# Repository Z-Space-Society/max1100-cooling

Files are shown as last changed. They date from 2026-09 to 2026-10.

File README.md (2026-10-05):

# max1100-cooling

Printed ducts for cooling the Intel Data Center GPU Max 1100, a passive 300 W
server card, with ordinary fans. First target is a single card in **Salmon**
(Lian Li LANCOOL 216 tower). The per-card part carries over to a four-card
plenum in a 4U chassis.

- [Dimensions](docs/dimensions.md): card, column and chassis measurements,
  datasheet and hand-measured
- [Cooling](docs/cooling.md): the problem, design decisions, fan choice, test method
- [RackChoice 4U](docs/rackchoice-4u.md): the quad's chassis — what fits, what's
  still unmeasured
- Project log and host notes live in SCNVault: `Projects/Max 1100 Notes/` for
  the single card, `Projects/QuadBox/` for the four-card appliance

## Terminology

Use these names every time. **Do not use front, back, top, bottom, left or
right on their own.** Left and right are only allowed with a named view (below).

### The card

```
                          SIDE VIEW (looking at the shroud side)

   I/O end                                                     tail end
     ┃ ┌───────────────────────── top edge ──────────────────────────┐
     ┃ │                                                             │▒ bay  ══ extension
     ┃ │                    shroud side (cover)                      │▒         bracket
     ┃ │                                                             │▒
     ┃ └──────┬▄▄▄▄▄▄▄▄▄▄▄▄┬───────── finger edge ───────────────────┘
     ┃        gold fingers
  I/O bracket

   ◀── into the card (−Z)                                   out past the tail (+Z) ──▶
```

```
                 TAIL VIEW (the default): standing past the tail end,
                 looking into the bay, shroud side up. Schematic, not to scale.
                 This is Rhino's Top view of the card adapter models.

                                   SHROUD SIDE  (+Y)
                ┌────────────────────────────────────────────────────┐  ┬
                │   ┌──────────────────────────────────────────┐     │  │
   FINGER EDGE  │ ● │▓▓▓▓▓▓▓▓▓▓▓▓▓▓▓▓ fin band ▓▓▓▓▓▓▓▓▓▓▓▓▓▓▓▓│     │  │  TOP EDGE
      (−X)   ◀──┤   │              bay opening                 │ 12V ├──▶   (+X)
                │ ● │      base plate · PCB · headers          │ 2x6 │  │
                │   └──────────────────────────────────────────┘     │  │ 38.64
                └────────────────────────────────────────────────────┘  ┴ thickness
                                    PCB SIDE  (−Y)
                ├──────────────────────── 111.15 height ─────────────┤

                ● = extension bracket mounting holes (finger side)
                +Z points out of the page, toward you (out past the tail)
```

| Term | Means | Avoid saying |
|---|---|---|
| **I/O end** | End with the PCIe I/O bracket. Air **exits** here. Sits at the rear of a case. | back, rear, front |
| **Tail end** | Opposite end: the bay, fins, 12V-2x6, extension bracket. Air **enters** here. | front, back, end |
| **Finger edge** | Long edge with the PCIe gold fingers. Plugs into the board. | bottom |
| **Top edge** | Long edge opposite the fingers. Black strip (bridge cover?) runs along it. | top (alone) |
| **Shroud side** | Face covered by the shroud cover. The fins sit against it inside. Older notes: "shroud top". "Up" in the tail view. | top, front, cooler side |
| **PCB side** | Opposite face: the back of the PCB, where the extension bracket plate sits. "Down" in the tail view. | back, bottom |
| **Length** | I/O end → tail end. 266.7 (312 with extension bracket). | |
| **Height** | Finger edge → top edge. 111.15. | width |
| **Thickness** | Shroud side → PCB side. **38.64** measured, not the datasheet's 34.35. | width, depth |

### The tail end

| Term | Means |
|---|---|
| **Shroud end plane** | Plane of the shroud's end at the tail. Z = 0. All "into the card" and "past the tail" distances measure from here. |
| **Bay** | The recessed pocket at the tail end. Not a flat face. |
| **Opening** | The bay's mouth at the shroud end plane, where the tube goes in. |
| **Fin band** | The fin stack as seen in the bay: a band along the shroud side. |
| **Fin face** | The fins' exposed ends, 37 to 39 into the bay. |
| **Fin throat** | The area of fin face air can actually enter. Not yet calipered. |
| **Connector column** | The part of the bay beside the fins with the 12V-2x6 (top-edge side), headers (CNSPI1, CNAMC1, SWAMC1). Stays open to the room. |
| **12V-2x6** | Power connector. Top-edge side of the tail end, toward the PCB side. Plugs in axially, needs ~35 straight cable. |
| **Extension bracket** | Flat L-plate on the PCB side, reaches 45 past the tail to a server card guide. Stays on: its screws now clamp the card adapter to the card. |
| **Bracket mounting holes** | The two threaded holes on the card, finger side of the tail end, that the extension bracket screws into (Torx T8). 19 apart (Katie). The adapter's bracket holes line up with these. |
| **Bracket plate** | The part of the extension bracket lying against the PCB side. |

### Card adapter (current design)

The printed piece that joins the GPU's own parts (the bay, the shroud end
plane, the extension bracket) to the printed ducting. Everything after it
(flare, fan) plugs into it. The working base since 2026-09-21: Katie's Rhino
model, adjusted here.

```
   CARD ADAPTER V2 in the tail view: flange face toward you, tube going away into the bay.

                                      shroud side ↑
      ┌──────────────────────────────────────────────────────────────┐ ┬ 2
      │      ┌─────────────────────────────────────────────────┐     │ ┼
      │  ○   │                                                 │     │ │
      │      │           tube 76 × 22 outside, 16 deep         │     │ │ 22
      │      │           bore 73 × 19 (1.5 wall)               │     │ │
      │  ○   └─────────────────────────────┬──────────────────┬┘     │ ┼
      │                                    │ power notch      │      │ │ 14
      └────────────────────────────────────┘ 24 × 14          └──────┘ ┴
                                      PCB side ↓
      ├─ 10 ─┼──────────────────────── 76 ──────────────────────┼─ 9 ─┤
      finger edge ◀                                            ▶ top edge

      Flange 95 × 38 × 2.   ○ bracket holes Ø3, 19 apart, 4 out from the tube's
      finger-side face: one 4 in from the tube's shroud face, one 1 past its PCB face.
      Power notch: from the flange's PCB edge up to the tube; its top-edge side
      is flush with the bore's inside face.
```

| Term | Means |
|---|---|
| **Card adapter** | The per-card printed piece (`cad/card_adapter.py`): adapter tube + flange. Always its own piece, bolted to the card by the extension bracket. One per card; the quad reuses it unchanged. Not "shroud": that's the GPU's own cover. |
| **Adapter tube** | Rectangular duct that goes 16 into the bay (−Z). Plain "tube" inside `card_adapter.py` means this one. |
| **Bore** | The inside of the air path, 73 × 19, where the air goes. Runs through the adapter tube, the flange and the plenum tube at the same section, with no step. |
| **Flange** | Plate on the shroud end plane. Sets the depth and carries the bracket holes. |
| **Seat** | A 1 layer added on the flange face (+Z, toward the fan) that stops 1 short of the bore, except along the power notch's length on the PCB side, where it runs up to the bore (the strip left there would be too thin to print). The rebate it leaves around the bore's mouth is where the next part sits; the layer's face is the print face. Draft, V4. |
| **Power notch** | Cutout in the flange's PCB side, top-edge end, clearing the 12V-2x6. |
| **Scoop** | The tube's PCB-side wall carried on past the tube's end, angled toward the PCB side, so air reaches the fins on that side. Goes in by hooking it over the power plug and sliding it home. Stops short of the top-edge end to clear the header pins in the bay. |
| **Bracket holes** | Two Ø3 holes in the flange's finger-side end. The extension bracket's screws pass through them into the card's bracket mounting holes. |
| **Fan connector** | Reference outline in the .3dm (120 × 120) for the fan-side piece. Not solid. |
| **Flare** | Salmon-only piece: card adapter → fan (`cad/flare.py`). A lip sits in the adapter's seat; it bolts to the bar. Draft: V1 is for one 140, 130 past the tail end with the fan on. |
| **Bar** | The extension bracket's outer end: a 96 × 10 strip parallel to the PCB side, 35 to 45 past the shroud end plane, a hole at each end 88 apart. The flare's bar pad lies on its shroud-facing face. |
| **Bar pad**, **ears** | On the flare: the PCB-side wall thickened to a flat face on the bar, and the two tabs past the flare's sides that carry its holes over the bar's holes. |
| **Fan plate** | The flare's 140 × 140 end. The fan bolts onto it face to face; the duct behind it is smaller than the fan. |

### Quad (brainstorming)

Nothing is decided. These are names for things being talked about, so we're
arguing about the same objects — not a description of a design. Several fan
layouts are live; see [cooling](docs/cooling.md#quad). The only thing drawn so
far is the comb, and that's a fit test.

| Term | Means |
|---|---|
| **Plenum** | The quad's chamber beyond the card adapters: one box, fed by the fan panel, feeding all four. Maybe more than one printed piece. Never one piece with the adapters. |
| **Plenum tube** | One of the four passages from the plenum to a card adapter (+Z from the flange face). Same 73 × 19 bore as the adapter tube — the same air path, split across two parts. |
| **Slip joint** | Where a plenum tube meets a card adapter. Whatever its final form, it is the **tolerance joint**: it absorbs the slot-to-slot error so neither part has to be accurate. |
| **Fan panel** | The plenum's front face, carrying the fans that feed it. Its slot-side edge is flush with the card column's wall, so anything wider overhangs toward the PSU side. |
| **Front stage** | Fans on the case front wall feeding the plenum. There for **filtered room air**, not for pressure. |
| **Collar** | A short sealed duct between fan stages, or from the front stage into the fan panel. Must be a closed ring, not corner posts, or series fans lose their series. |
| **Transition** | The printed piece from the fan face to the four plenum tubes, where the duct changes section. |
| **Card column** | The four cards at 40.64 slot pitch: 160 measured across the cards, bore band 141. Sits against one side wall, so everything wider has to overhang toward the PSU. |
| **Tail box** | Option G: one box from the case front wall back to the four tail ends, sealing on the card column instead of on four separate adapters. Bolts to the floor standoffs, the top rail and the front wall. |
| **Tail wall** | The tail box's face at the tail end plane — the thing the user called the "back plate". Closes everything except the four bay openings. |
| **Comb** | Spine plus teeth spanning the column, holding the teeth on the 40.64 pitch. Part of the tail wall. `cad/comb.py`. |
| **Comb tooth** | One tooth, in the gap between two adjacent cards — the "spacer between the GPUs". Seals the gap, locates the card sideways, and in a floor-mounted comb carries its weight. 2.0 thick. |
| **Tail box gauge** | The tail box's outline at card-top height: the comb plus rails to the case wall and a bar at the front plate. A fit test, `cad/tail_box_gauge.py`. |
| **Case side rib** | An L flat on the case wall beside card 4. The rib fills the 12 between card 4's shroud side and the case wall, case floor to 157 (top of the power buttons), 10 in from the tail end plane. A rail turns at its top and runs along the wall to the case front, the edge the case's top cover seals against. A tab screws it to the wall standoff. `cad/case_side_rib.py`. |
| **Tail box demo** | An upside-down L, closed by the case wall: a 1.2 side wall to the case floor against card 1, a 1.2 lid out to the case wall, teeth sealing the full gap. Held on by the teeth. A show model, `cad/tail_box_demo.py`. |

### Views

Say which view you mean before saying left or right.

| View | How you look | What's where |
|---|---|---|
| **Tail view** (the default) | Standing past the tail end, looking into the bay, **shroud side up**. Rhino's Top view. | Finger edge **left**, top edge and 12V-2x6 **right**, PCB side down |
| **Salmon installed** | Standing at the case front, looking in toward the rear | Card horizontal. Shroud side **down**, finger edge **right** (into the board), top edge toward the glass, tail end toward you |

### CAD frame

The CAD frame is Katie's Rhino frame. It's right-handed, so nothing is
mirrored.

| Axis | + direction | In the tail view |
|---|---|---|
| **X** | Toward the top edge | Right |
| **Y** | Toward the shroud side | Up |
| **Z** | Out past the tail. − = into the card | Toward you |

Z = 0 is the shroud end plane. In XY, the card adapter measures from **REF**,
the tube's outer corner at the finger side and PCB side. REF is placed at
Katie's Rhino coordinates (−1.5259, −7.3609) so our files overlay hers exactly.

## Parts

| Script | Output | Status |
|---|---|---|
| [`cad/card_adapter.py`](cad/card_adapter.py) | `rhino/max1100-card-adapter-v4.3dm`, `stl/max1100-card-adapter-v4.stl` | **Card adapter V4** (`CURRENT`): V3 + Ø3.4 bracket holes, the scoop 4 short of the top-edge end, and the seat (flange 3 thick overall, rebate 75 × 21 × 1 deep around the bore, none along the power notch). Not yet printed |
| | `rhino/archive/*-v2.3dm`, `*-v3.3dm`, `stl/archive/*-v2.stl`, `*-v3.stl` | Earlier versions, archived as the record. V3 was printed and fitted. `make parts` writes only `CURRENT`; to rebuild an older one, point `CURRENT` at it (it writes to `rhino/` and `stl/`, not the archive) |
| [`cad/flare.py`](cad/flare.py) | `rhino/max1100-flare-v2.3dm`, `stl/max1100-flare-v2.stl` | **Flare V2** (`CURRENT`): draft, for one 140 fan in Salmon. Two-stage 45° taper, lip into the adapter's seat, bar pad and ears onto the extension bracket's bar. V1 + the PCB-side wall 2 thick all the way across (no step over the power notch). The bar's position through the thickness is guessed. Not yet printed |
| | `rhino/max1100-flare-fit-test-v2.3dm`, `stl/max1100-flare-fit-test-v2.stl` | **Flare fit test V2** (`FIT_V2`): the flare cut off at the bar's far edge, shroud-side wall left straight. Print cut end down. Not yet printed. V1 of it was printed 2026-10-05: the lip didn't drop into adapter V4's rebate or line up, not yet diagnosed. V1 files are in the archive folders |
| [`cad/comb.py`](cad/comb.py) | `rhino/max1100-comb-v1.3dm`, `stl/max1100-comb-v1.stl` | **Comb V1** (`CURRENT`): fit test for the quad. Printed and fitted 2026-09-23 — spans the four cards, teeth into all three gaps |
| [`cad/tail_box_gauge.py`](cad/tail_box_gauge.py) | `rhino/max1100-tail-box-gauge-v1.3dm`, `stl/max1100-tail-box-gauge-v1.stl` | **Tail box gauge V1** (`CURRENT`): fit test for the tail box. Comb V1 plus an open ring out to the case wall (172) and the front plate (165), both 1 short. Not yet printed |
| [`cad/tail_box_demo.py`](cad/tail_box_demo.py) | `rhino/max1100-tail-box-demo-v1.3dm`, `stl/max1100-tail-box-demo-v1.stl` | **Tail box demo V1** (`CURRENT`): an upside-down L: a 1.2 wall to the case floor against card 1, a 1.2 lid out to the case wall, teeth to the finger edge. For showing people, not for use |
| [`cad/case_side_rib.py`](cad/case_side_rib.py) | `rhino/max1100-case-side-rib-v1.3dm`, `stl/max1100-case-side-rib-v1.stl` | **Case side rib V1** (`CURRENT`): 11.5 thick throughout. Rib 10 × 157 beside card 4, rail 10 tall to 1 short of the front wall, tab with a Ø7.5 pocket over the wall standoff and a Ø3.6 screw hole. Not yet printed |
| [`cad/check_v1.py`](cad/check_v1.py) | (none) | Confirms the card adapter's `V1` still reproduces Katie's `.3dm` |
| [`cad/archive/`](cad/archive/) | `stl/archive/`, `images/archive/` | Superseded: card part v2.1, box fit tests, hole coupon. Kept for the record. `stl/archive/` and `rhino/archive/` also hold card adapter V2 and V3 |

Rhino models are in [`rhino/`](rhino/): Katie's originals, plus the `.3dm`
each script writes. Parts are built from extruded profiles in
[`cad/profiles.py`](cad/profiles.py), which writes each one as a native Rhino
extrusion (editable in Rhino) and as a single watertight STL.

**Print settings** (match the coupons or the numbers don't transfer): PETG,
0.2 mm layers, 4 perimeters, 20 % infill, no supports. Orientation is in each
script's docstring — card adapter flange down, flare fan plate down, comb flat on its X-Y face,
tail box gauge ring-face down, tail box demo lid down, case side rib wall
side down.

## Build

```sh
make setup     # uv venv + pinned trimesh, manifold3d, numpy, scipy, rhino3dm
make parts     # regenerate the current parts (.3dm + .stl)
make check     # V1 still matches Katie's Rhino file
make archive   # regenerate stl/archive/
```

All dimensions are mm. File names use hyphens (`max1100-card-adapter-v2.3dm`);
Python scripts use underscores so they can import each other.

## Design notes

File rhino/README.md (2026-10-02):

# Rhino models

Rhino 8 `.3dm`, mm. Two kinds of file live here:

- **Katie's originals** (`1100-singleshroud-v1.3dm`): drawn by hand in Rhino.
  Don't edit them in place; they're the reference `make check` compares
  against.
- **Generated** (`max1100-*.3dm`): written by a script in `cad/`. Every object
  carries a `source` Attribute User Text naming the script. Changes made here in
  Rhino get overwritten on the next `make parts`, so either change the script,
  or save a Rhino edit under a new name and we'll port it back.

All card adapter files share Katie's coordinates. The Top view is the tail
view (README, "Views"), so they overlay one another exactly.

| File | Part | Made by | Notes |
|---|---|---|---|
| `1100-singleshroud-v1.3dm` | Card adapter V1 | Katie, 2026-09-18 | Tube 76 × 20 × 16, flange 95 × 36 × 2, power notch 25 × 14, Ø3 bracket holes 19 apart. `cad/card_adapter.py` `V1` reproduces it (holes rounded 0.005) |
| `max1100-card-adapter-v4.3dm` | Card adapter V4 | `cad/card_adapter.py` | V3 fixes: bracket holes Ø3.4, scoop stops 4 short of the top-edge end (header pins). Plus the seat on the "Seat" layer: 1 added on the flange face, rebate 75 × 21 × 1 deep around the bore, none along the power notch. Current |
| `archive/max1100-card-adapter-v2.3dm` | Card adapter V2 | `cad/card_adapter.py` | Tube 22, flange 95 × 38, power notch 24 × 14, bracket holes moved 1 toward the finger edge and 1 toward the shroud side. Superseded, never printed |
| `archive/max1100-card-adapter-v3.3dm` | Card adapter V3 | `cad/card_adapter.py` | V2 + scoop on the "Scoop" layer: PCB-side wall goes 10 deeper, angled 5 toward the PCB side. Printed and fitted 2026-09-22. Superseded |

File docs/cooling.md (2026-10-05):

# Cooling

All mm. Names follow [Terminology](../README.md#terminology). See also
[dimensions](dimensions.md) and [the chassis](rackchoice-4u.md). The project
log and host notes are in SCNVault: `Projects/Max 1100 Notes/` for the single
card, `Projects/QuadBox/` for the four-card appliance.

## Problem

The Max 1100 is passive and built for a server's front-to-back fan wall. It
needs to be ducted to ordinary fans, first as a single card in Salmon (LANCOOL
216 tower), then as four cards in a 4U chassis.

## Thermal facts

From datasheet 817799.

- 300 W. 12V-2x6 power connector.
- GPU and HBM Tj max 105 °C. Card shuts down at 125 °C.
- Required airflow (Figure 6-3): `LFM = 0.014x³ − 0.6694x² + 13.324x + 150.78`,
  where x is the approach air temperature in °C. About 285 LFM at 25 °C and
  400 LFM at 35 °C.
- Figure 6-4, the airflow impedance curve, **hasn't been read yet**. It
  settles the fan choice.
- The datasheet doesn't dimension the heatsink, fin opening or tail bay, and
  there's no separate thermal design guide for this card.

## Design

- **Push.** The fan is at the tail end. Air goes through the fins and out the
  I/O end, which matches both a server's airflow and the tower's own
  front-to-back flow.
- **Card adapter** (`cad/card_adapter.py`, V4):
  - The tube goes 16 into the bay.
  - The flange sits on the shroud end plane.
  - The extension bracket's screws go through the bracket holes into the
    card, so the bracket clamps the adapter on.
  - The power notch clears the 12V-2x6, outside the tube.
  - Bore 73 × 19.
  - The scoop: the PCB-side wall carries on 10 past the tube's end, angled 5
    toward the PCB side. It widens the air stream onto the fins on that side
    and cuts the air leaking back out through the power notch. It goes in by
    hooking it over the power plug and sliding it home, and stops 4 short of
    the top-edge end to clear the header pins there.
- **The same adapter serves 1 or 4 cards.** It is always its own piece,
  bolted to the card by the extension bracket. Only the fan side changes:
  - Salmon gets a flare from the adapter to one fan.
  - The quad gets a plenum feeding four adapters, joined by a slip joint.
  - Neither is designed yet.
- **No 90° 12VHPWR adapter.**

## Airflow

- At 285 LFM through the ~1390 mm² bore, the card needs only about 4 CFM.
  Volume isn't the problem; **static pressure** through 267 of dense fins is.
- **But that 4 CFM may be 2.75× too low.** It assumes the datasheet's LFM is
  referenced to our bore area. Approach-velocity figures are normally
  referenced to the card's slot cross-section. That was taken as
  34.35 × 111.15 = 3818 mm², giving **~12 CFM per card, ~47 CFM for the
  quad**. The card measured 38.64 on 2026-09-23
  ([dimensions](dimensions.md#thickness-3864-not-3435)), so the area is
  really 4295 mm² and scenario B is about **12 % higher, ~53 CFM**. The
  static estimates below still use 47 and have not been redone; the
  correction pushes every one of them the same way and changes no ranking. It changes
  how much fan the quad needs: at 17 CFM total a front stage plus two panel
  fans is heavily over-fanned and every fan runs near shutoff, where they are
  stall-noisy for no benefit; at 47 CFM it's about right. The Figure 6-4
  impedance curve's x-axis should settle which area the LFM refers to.
- **Quiet is the binding constraint**, because these machines live in a
  closet. Fan size is still open. A bigger fan turns slower at the same flow.
- A quiet 120 or 140 makes about 2 mmH₂O, and full 300 W likely needs several
  times that. **Plan on fans in series** — see [Fans](#fans) for why series
  and not more fans side by side.
## Fans

### Pressure scales with rpm², so the model matters

Two knobs, and they do different things:

- **Width (parallel) buys flow**, which is usually the resource in surplus.
- **Depth (series) buys pressure**, which is the scarce one. Pressure adds.

**But width only stops helping once you're already far left on the curve** —
that qualifier matters and an earlier version of this note left it off. Going
2 × 140 across → 3 across moved the estimate from ~4.2 to ~4.4 mmH₂O, because
at 21 % of free air those fans were already on the flat part. One 120 at
scenario B is at 61 % of free air, on the *steep* part, and there a second fan
across is worth a lot. Check where on its curve a fan actually sits before
assuming width is wasted.

And because **pressure ∝ rpm² while flow ∝ rpm**, you can't trade width for
quiet: slow a wide array down and static collapses quadratically. The quiet
way to get static is *series at reduced rpm* — three fans at 1500 rpm against
one at 2500 makes about the same pressure and is roughly **6 dB quieter**
(−11 dB per fan from the rpm ratio, +4.8 dB for having three).

### 120 or 140: the chassis settles it

**A 140 fan does not mount on the RackChoice front plate.** Its upper screw
holes land 9.5 inside the power button cutout — see
[dimensions](dimensions.md#rackchoice-4u-chassis). Not tight; it doesn't fit.
That takes the 140 out of the quad duct regardless of its aerodynamics, and
the P14 Pros bought on 2026-09-22 go to Salmon, which is the first target and
has room for them.

Manufacturer figures, both PWM with PST:

| | P12 Pro PST | P14 Pro PST |
|---|---|---|
| Part # | ACFAN00307A | ACFAN00319A |
| Static | **6.9 mmH₂O** | 5.2 |
| Free air | 77 CFM | 110 |
| Range | 600–3000 rpm | 400–2500 |
| Thickness | 25 | 27 |

The 120 makes **33 % more static** and moves 30 % less air — the usual trade,
and pressure is the scarce resource here. Three in series:

| | 120 | 140 |
|---|---|---|
| Scenario A, 17 CFM | **~16.2 mmH₂O** | ~13.2 |
| Scenario B, 47 CFM | ~7.7 | ~8.6 |

So the 120 wins scenario A outright and loses B by ~10 %. A scaling-law
estimate had put the P12 Pro at ~5.5 mmH₂O; the two fans aren't geometrically
similar, so that ran 20 % low. Use the published figures, not the scaling law.

### Which Arctic P14

Same P-series aerodynamics across the line; what changes is the rpm ceiling,
the control type and the bearing. The rpm ceiling is the one that bites, via
that rpm² law:

| | P14 | P14 Pro PST | P14 Pro PST CO |
|---|---|---|---|
| Part # | — | ACFAN00319A (5-pack) | ACFAN00316A |
| Max rpm | 1700 | 2500 | 2500 |
| Static, max | ~2.4 mmH₂O | 5.2 | 5.2 |
| Free air | ~75 CFM | 110 | 110 |
| Control | 3-pin DC | PWM, 400–2500, stops below 5 % | PWM, same |
| Bearing | FDB | FDB | Dual ball |

**The plain P14 is not usable here.** (1700/2500)² = 0.46, so it makes
~2.4 mmH₂O — less than half. Worked through option C below, three in series:
~5.6 mmH₂O at scenario A and **~2.4 at scenario B**, against an estimate that
300 W needs several times 2. Its 3-pin DC control also gives roughly 2:1 of
usable range against the Pro's 6:1, and the test method needs fan speed driven
from GPU temperature. A 1700 ceiling also leaves nothing in reserve when a
card hits 95 °C.

**PST is worth having for a series stack.** Series stages must pass identical
flow or one becomes a restriction, so they need a common PWM signal. PST
daisy-chains them off one header and they track exactly — the wiring problem
solved by the connector.

**CO vs not is a trade, not an upgrade.** Dual ball tolerates heat better,
which matters for 24/7 in a warm closet; FDB is quieter, and quiet is the
binding constraint. Not worth holding out for: if FDB life proves short it's a
swap, not a redesign.

### Buying

- **P14 Pro PST 5-pack, ACFAN00319A**, ~$80 at Memory Express (2026-09-22),
  ~$16/fan. Stock was thin — one pack online, nothing in the Lower Mainland
  stores.
- Five doesn't cover everything at once. Option C wants 3 duct + 1 CPU + 1
  spare; option B wants 4 + 1 and no spare; and **Salmon is the first target**
  and wants two for the series pair. Expect to split a pack and buy a second
  when the quad gets real.
- **Salmon length budget:** 392 GPU clearance − 266.7 card = 125 behind the
  card. The extension bracket takes 45 of it.

## Quad

Four cards in the RackChoice 4U ([rackchoice-4u](rackchoice-4u.md)), board
slots 1, 3, 5, 7, standing upright, tails facing the case front, the column
against one side wall. Worked through 2026-09-22.

**Status: brainstorming.** Nothing here is decided and nothing here is
retired. This is a record of options and the reasoning behind them, written
down so ideas don't get lost — not a decision log.

The one thing the user has said out loud is that the **card adapter** is its
own piece, bolted to each card by the extension bracket, with a **plenum**
beyond it (2026-09-22). Even that gets revisited if hardware says otherwise.

Everything else — fan sizes, counts, layout, how the plenum splits — is an
option on the table. Where a number looks firm, it's firm *given that option*.
Options that are currently behind are kept below **with the reason they're
behind**, so they can be picked back up when something hits a dead end.
Nothing gets decided until we've played with real hardware in the case.

### Ground rules that survive most changes

- The four adapters are parallel branches: flow adds and pressure doesn't. The
  quad needs **the same static pressure as one card, at four times the flow**.
  That means more of the same fan, not a stronger one.
- **The risk is uneven distribution.** The plenum's cross-section needs to be
  several times the total bore area (4 × 1387 = 5548 mm²), or the card
  nearest the fans takes the air.

### Architecture

Two stages, separate pieces:

1. **Card adapter**, one per card, bolted to the card by the extension
   bracket's own screws. The same part for Salmon and the quad.
2. **Plenum** beyond it — possibly itself two pieces — joined to each adapter
   by a slip joint.

**The slip joint is the tolerance joint, and that is the main reason the
plenum can't be one piece with the adapters.** Slot pitch is nominally 40.64,
but across four slots on a real board in a real case the four flange faces
won't be coplanar or evenly spaced; expect ±1 to 2 of accumulated error. Each
adapter gets screwed down wherever its card happens to sit, and the plenum
then floats onto four stubs with a few mm of axial travel and about 1 of
lateral float, with foam tape taking up the rest. Nothing has to be accurate.

Two more reasons for the split: the bracket screws go in axially right past
the bore wall (T8, hole centres 4 from the tube's outer face, ~2.3 clear at
the hole edge), so nothing can be in the way while an adapter is fitted; and
pulling one card shouldn't mean removing the plenum.

### The slip joint

Common to every fan option below.

- **Male on the adapter, female on the plenum.** A plenum tube plugging *into*
  the bore would have to be smaller than 73 × 19 and would choke the tightest
  section in the whole path. Male-on-the-adapter keeps the bore 73 × 19 end to
  end with no step.
- **Three-sided stub**, skipping the finger-side face. That leaves the T8 a
  clear shot at both bracket holes and clears the extension bracket's plate,
  which lies on top of the flange at that end. The socket seals on three faces
  and lands on the flange face at the fourth.
- A +Z stub breaks the current flange-down print orientation, because material
  would sit on both sides of the flange. Untested options: print on its side
  (axis horizontal, the bore's upper face bridges 19, no supports); stub-down
  with a 45° flare out to the flange (supportless and good for airflow, but
  adds up to 14 of height); or make the stub a separate printed collar. Test
  print before committing — it also changes layer orientation at the
  bracket-hole bosses, which the screws clamp through.

### Column geometry

Slot pitch 40.64, measured from the slot-side case wall with card 1 against it.
Derived from `card_adapter.py` V4, not measured in a case.

| | Card 1 | Card 2 | Card 3 | Card 4 |
|---|---|---|---|---|
| Flange, 38 wide | 0–38 | 40.6–78.6 | 81.3–119.3 | 121.9–159.9 |
| Bore, 19 wide | 15.5–34.5 | 56.1–75.1 | 96.8–115.8 | 137.4–156.4 |
| Bore centre | 25 | 65.6 | 106.3 | 146.9 |

- Flange column 160 wide. Bore band 15.5 to 156.4, centred at 86.
- **2.64 between adjacent flanges** — but the flange only exists at Z = 0 to 2.
  Past it the gap between adjacent *bores* is **21.6**, so four plenum tubes
  with 1.5 walls still have 18.6 of air between them. Per-card tubes are not
  the problem.
- What *is* in that 21.6 is each card's **extension bracket plate**, running
  Z = 0 to +45 in its card's plane. So either the plenum tubes stay short
  stubs onto the flange face, or the web between them needs a slot per card.

### How the fans feed it — the options

Three shapes are on the table. They share everything above (adapters, slip
joint, column geometry) and differ only in what sits between the front of the
case and the plenum.

| | Fans | Front width used | Est. static, scenario B | Biggest printed part |
|---|---|---|---|---|
| **E** — 1 across × 3–4 deep | 3–4×120 | 120 | ~7.7 / ~10.2 | transition, 121 wide |
| **A** — fan panel + collar | 2×120 panel, 2×140 front | 280 | ~8.4 | fan panel, 240 wide |
| **B** — 2 across × 2 deep | 4×140, all in the duct | 280 | ~8.4 | transition, 280 wide |
| **C** — 1 across × 3 deep | 3×140, all in the duct | 140 | ~8.6 | transition, 141 wide |
| **F** — 2 across × 2–3 deep | 4–6×120 | 240 | ~8.0 / ~11.9 | transition, 240 wide |
| **G** — tail box | E's stack, in a box | 120–240 | ~8.6 (no transition loss) | tail wall, ~170 wide |

**G is a different shape of thing and not a competitor to the others.** It
replaces the plumbing — adapters, slip joint, transition, collar — with one
box, and E's fan stack sits inside it unchanged. Read the fan rows as the
question of how many fans, and G as the question of what holds them.

**Currently leaning E** (2026-09-23) for the fan stack. The chassis decided most of it: a 140
doesn't mount on the front plate, which takes B and C out on hardware rather
than on aerodynamics, and A used 140s for its front stage. F is the fallback
if E turns out short on pressure, but it's side-by-side and a 240-wide part,
which the user would rather avoid — a fourth fan in series on E is the
cheaper way to the same place. Still a lean, not a decision.

All four estimates assume the **P14 Pro** at 2500 rpm. Width buys flow, depth
buys pressure, and pressure goes as rpm² — see [Fans](#fans), which is why
three options out of four stack in series rather than spreading out.

### Option G — the tail box

Proposed 2026-09-23. One box from the case front wall back to the four tail
ends — the 165 from the grill to the flange faces — bolted to the six floor
standoffs, to the top rail and to the front wall, with a lid. The fans mount
at the front of it. **It seals on the card column instead of on four separate
adapters**, so the card adapter, the plenum tubes and the slip joint all come
out.

**The one hardware result so far went its way.** Comb V1 (`cad/comb.py`), a
rigid bar with three teeth on the 40.64 pitch, fitted the four installed cards
on 2026-09-23 — see [dimensions](dimensions.md#quad-column). A single rigid
part spans the column, which is what the whole idea rests on.

#### What it deletes

- **The slip joint**, and with it the hardest problem in the quad: four
  joints each absorbing slot-to-slot error. One compliant perimeter replaces
  four tolerance joints. (The split between adapter and plenum still has two
  other justifications — axial screw access and pulling one card without
  disturbing the rest — so this doesn't retire the adapter architecture, it
  removes its main argument.)
- **The transition.** The box *is* the plenum, so there's no 3D contraction to
  design, print or seal, and no ~121 × 120 × 75 part.
- **The collar and the front stage.** A box bolted to the front wall breathes
  filtered room air by construction. That was worth more than a fan stage —
  see [the front stage](#front-stage-as-option-a-uses-it) for why — and here
  it costs nothing.
- **The slant.** The fan centre is fixed at 77.9 and the bore centre is 52–70;
  a duct had to slant between them. A box just contains both.
- **The power notch problem.** In the adapter, the notch is an open cutout
  that lets air out of the bay before it reaches the fins
  ([dimensions](dimensions.md#power), parked, never measured). Inside the box
  it opens into the plenum, not the room, so there's no pressure across it and
  nothing to leak.

#### Inlet area decouples from fan area

A duct bolted to one grill position inherits ~1.2 mmH₂O of inlet loss. A box
whose front face spans two positions with a fan on one drops that to ~0.30 —
**~0.9 mmH₂O recovered for nothing**, more than a fourth fan in series is
worth per stage. A box can breathe through more grill than its fans cover; a
duct can't.

The counter-pressure is option D's surviving conclusion: **at least one front
position stays with the rest of the machine.** With three positions, a box
spanning two leaves one for the CPU, PSU and drives. That's the trade to keep
an eye on, and it argues for a box no wider than it needs to be.

#### The comb, and what the teeth do

Four jobs in one part: seal the gap between cards, locate each card sideways,
carry the column's 5.2 kg, and replace the hanging card-guide rail ([rackchoice-4u](rackchoice-4u.md#tail-support)).
The [leak arithmetic](dimensions.md#quad-column) is why it's not optional —
the gaps are a nearly free bypass straight into the case, so unsealed they
take the air whatever they measure.

- **Teeth are 2.0**, which went into all three gaps as printed. Confirmed
  over the last 25 before the tail end plane — the region a tail wall seals
  in. Deeper than ~45 along the card, past the extension bracket plate, the
  gap may open up.
- **A floor-mounted comb can't reach back past the tail plane.** That space is
  over the motherboard. So the V1 test comb hangs from the top edges instead,
  which also makes it a single constant cross-section to print. Where the
  real one lives depends on the motherboard's front edge, still unmeasured.
- **Support vertically, with clearance, never by clamping.** The box is
  registered to the case floor and the cards to the board; a rigid tie between
  them preloads the PCIe connectors with the whole tolerance chain.
- **Removing the extension brackets** is then on the table: their job is to
  reach a card guide, which the comb does better, and they currently occupy
  the inter-card gap from Z = 0 to +45 where the teeth want to be. Reversible.

#### What it gives up, and what it risks

- **The scoop.** The adapter's only genuine airflow claim is aiming the stream
  at the PCB-side edge of the fin throat. A box pressurises the opening but
  doesn't aim anything. Worth re-testing as a bay insert — a scoop with no
  flange and no bracket holes — *after* the box works, and only once the fin
  throat has been calipered. It may never have been needed.
- **Salmon still needs the card adapter.** Single card, no box, the fan has to
  attach to something. V4 and the flare are untouched by any of this.
- **Perimeter leak scales with box size.** A 1 mm gap around a 200 × 140 box
  perimeter is ~700 mm², 13 % of bore. Keep the box to the column's width, not
  the case's.
- **Print size.** 165 deep × 160–200 wide × ~140 tall is nobody's 220 bed.
  Likely a printed frame with flat panels, or a folded aluminium floor piece
  carrying printed parts, rather than an all-printed box.
- **Fan vibration.** Bolting fans to the sheet front plate will make the panel
  sing, and quiet is the binding constraint. Soft-mount them to the box.

#### What it needs measured

Beyond the whole [not-yet-measured list](dimensions.md#not-yet-measured), four
belong to this option specifically: the **motherboard's front edge** (where
the floor piece can start), **which end of the column** the 12 of case-wall
clearance sits at, the **standoff thread and positions**, and **which grill
positions** sit in front of the column. Plus one from the photo: the row of modules in sheet-metal
brackets between the front bar and the board is in the box's footprint —
whatever it is, does it stay?

### Option E — one 120 wide, three (or four) deep

**Currently the strongest**, and the one the user prefers (2026-09-23): no
side-by-side, one narrow printed transition, and it's the only fan size that
mounts on the front plate at all.

Depth, from measured chassis numbers ([dimensions](dimensions.md#rackchoice-4u-chassis)):

| | From the grill |
|---|---|
| Three fans (25 each) | 0–75 |
| or four fans | 0–100 |
| Extension bracket tips | 120 |
| Duct | 100–165 (65 with four fans, 90 with three) |
| Flange faces | 165 |

**Four deep fits** inside the clear space before the bracket tips, with 65
left for the transition — a 20° half-angle contraction, comfortable. A 5-pack
covers four plus a spare. That's the lever if the impedance curve turns out
harsh: scenario B goes from ~7.7 at three deep to **~10.2 at four**, before
grill losses. Run three if the curve is benign.

**Geometry.** A 120 frame against the 140.9 bore band means the duct has to
*expand* ~10.5 per side laterally while contracting 120 → 73 vertically, so
it's a 3D transition rather than the 2D squeeze a 140 would have given. At
65–90 of length the lateral half-angle is 7–9°, inside the no-separation rule.
Net area 10,029 → 5,548 = **1.81:1**, gentler than a 140's 2.28:1. The part is
about **121 × 120 × 75**.

The fan's centre is fixed at 77.9 above the case floor by the plate's screw
holes, while the bore centre is an estimated 52–70, so the duct slants down
slightly on its way back. Measuring the bore centre settles how much.

**The grill is the inlet, and it costs.** Loss goes as v², so spreading the
inlet across positions helps fast. At ~55 % open with a sharp-edge coefficient
of ~1.5, scenario B:

| Positions used | Hole velocity | Loss |
|---|---|---|
| 1 | 3.6 m/s | ~1.2 mmH₂O |
| 2 | 1.8 m/s | ~0.30 |
| 3 | 1.2 m/s | ~0.13 |

A fan bolted straight to one position inherits the ~1.2, taking scenario B
from ~7.7 to ~6.5. Worth checking whether the grill can be cut out — that
recovers it without an inlet box and without spending depth.

### Option C — one 140 wide, three deep

**The fan is the same width as the bore band.** Bore band, card 1's near edge
to card 4's far edge, is **140.9**. A 140 fan frame is **140**. Centre it on
the column and the frame lands 0.45 inside each end.

So **there is no lateral transition at all.** The duct squeezes in one plane
only: 140 tall at the fan down to 73 at the bores, 1.9:1 in the card-height
axis, nothing in the pitch axis. A 2D contraction, not a 3D flare — much
easier to print and more efficient. Total area ~127 round (the impeller
aperture, not the 140 frame) down to 5548, so **2.3:1**. Gentle.

The transition comes out about **141 × 140 × 65** — one piece on a 220 bed.
That's the main argument over option B, whose 280-wide transition won't fit
most beds and needs splitting plus a seam to seal.

Vertically it isn't centred: a 140 centred on the bore would want to sit below
the chassis floor, so the fan ends up ~10 high. The duct absorbs it.

**Depth budget** — 170 from flange faces (267) to front wall (437), three fans
is 75:

| | Depth from rear wall |
|---|---|
| Transition duct | 267–332 (65) |
| Fan 3 | 332–357 |
| Settling gap | 357–377 (20) |
| Fan 2 | 377–402 |
| Fan 1 | 402–427 |
| Slack | 10 |

One gap rather than two, prioritising duct length. Face-to-face series fans
work, just slightly less efficiently. Both gaps would leave ~45 of duct, a 22°
half-angle contraction — more abrupt but still acceptable.

**The spacers have to be closed collars.** If the gap between stages is open
to the case, the series effect is lost entirely: stage 1 dumps into the case
and stage 2 ingests case air. So the printed spacer is a continuous
**140 × 140 collar** with a ~127 bore and through-bolts at its corners, not
four corner posts. Trivial print, load-bearing for the whole idea. A 3-stack
with one gap is ~100 deep, so it needs M4 threaded rod or M4×110–130 screws,
not fan screws.

**Mounting: hang it off the front bar** (276–366, lid height). That bar runs
the full length of the duct and solves the cantilever problem. Should clear
vertically (duct top ~140, bar ~170) unless its down-turned flange drops more
than ~30 — still open ([rackchoice-4u](rackchoice-4u.md#open-issues)).

**The card-guide rail wants the same space.** The tail-support plan
hangs an aluminium angle from that same bar at 40.64 pitch to catch the
bracket tips at ~312 — inside the duct. Two things resolve it:

1. **The bracket plates themselves are harmless.** Thin sheet lying in each
   card's plane, parallel to the flow. In a single open duct volume behind a
   windowed back wall they just sit in the airstream, acting as flow
   straighteners if anything. Only per-card internal tubes with webs would
   collide. Another argument for short stubs and a windowed back wall.
2. **Put the rail above the duct.** The bore band tops out around 106; the
   bracket guide holes are at 117–125, so the rail clears by ~11–19. The duct
   covers the bore band only and the top-edge strip stays outside and above —
   consistent with the sealing call below. Both can hang off the same bar on
   shared standoffs.

**Part count:** four card adapters, one transition duct, two fan collars, one
hanger. Nothing over 141 wide.

### Option A — fan panel plus collar

Still on the table. It's behind C mainly on part size (a 240-wide fan panel
plus a separate collar, versus one 141-wide transition) and on mixing fan
sizes in series. But it has the shallowest duct of the three and keeps the
fans off the front bar entirely, so if the bar's flange turns out to foul the
duct, this is where to come back to.

**120 looks right for the panel, 140 looks hard.** In the card-height axis the bore centre is an estimated 52
to 70 above the chassis floor (the spread is where the flange sits in the
card's 111.15 height, compounded with the card height above
the floor, now measured at 127). A 120 resting on the floor centres at 60 — inside that band, so no
riser. A 140 on the floor centres at 70, at the top of the band or past it, and
wants 140 of card height where there is only ~111.

**Two 120s side by side into one shared plenum, not one fan per pair of
cards.** The column can only start at the slot-side wall, so two touching 120s
sit at centres 60 and 180, while the card *pairs* are centred at 45.3 and
126.6 — only 81.3 apart where the frames force 120. Split into two boxes,
fan 1 puts 41 of its face against the divider and fan 2 barely reaches card 3,
which starves. Shared, the imbalance disappears because all four branches draw
on a common static. Shared also means one fan failing costs flow, not two
cards.

- Fan panel 240 × 120, its slot-side edge flush with the column's wall, fans
  on the chassis floor. Aperture 28800 against 5548 of bore — **5.2×**, well
  into "pressure box, not duct".
- Fan 1 (0–120) sits directly over cards 1–3. Only fan 2 overhangs.
- **The offset toward the PSU side costs almost nothing.** The four adapters
  are parallel branches, so what each card gets is set by the static pressure
  at its flange, not by where a fan points. At this flow the fans are far from
  free air and make no coherent jet, and the fin stack dominates the loop hard
  enough to wash out upstream non-uniformity.
- **Taper the PSU-side end** of the plenum inward, from the fan face back
  toward the column, rather than leaving a square corner. That turns fan 2's
  outer 84 back into the box instead of parking a dead recirculation pocket.
- More pressure, if needed, comes from stacking a second 120 behind the first.

#### Front stage, as option A uses it

Two 140s on the case front wall, sealed by a short collar into the face of the
two 120s. The **reasoning here applies to every option** — B and C simply put
the front fans inside the duct instead of feeding a panel through a collar.

**The reason is approach air temperature, not pressure.** The datasheet curve
wants 285 LFM at 25 °C and 400 LFM at 35 °C: ten degrees of preheat costs 40 %
more airflow to hold the same die temperature. An unsealed panel feeds the
cards case air, downstream of a ~1.5 kW PSU and the CPU. A sealed collar feeds
them filtered room air. That's worth more than another fan stage.

Secondary: two 140s is 39200 of fan face against 28800 for two 120s, 36 %
more, so lower rpm for the same flow. Quiet is the binding constraint.

- 280 across into a 240 panel is a **contraction**, the forgiving direction.
  Contractions tolerate being abrupt; expansions don't. A few cm is plenty.
- **Same rotation, same PWM signal** on both stages. Series stages pass
  identical flow, so if their curves drift apart one stage becomes a
  restriction. PST daisy-chaining handles this.
- The ~30 gap is a feature, not a compromise: stage 1's swirl dies before
  stage 2 sees it. Better than bolting fans face to face.
- Leave the remaining ~140 of front width open for CPU, PSU and drives. Don't
  seal the whole front to the duct — the stock 80 mm rear exhausts are
  reportedly loud and shouldn't be leaned on.
- Contingent on the front wall behind the door being open
  ([rackchoice-4u](rackchoice-4u.md#open-issues), issue 5).

#### Depth budget for option A

Card tail at ~267 from the inside of the rear wall, front wall at ~437
([rackchoice-4u](rackchoice-4u.md), scaled from photos, ±10). About 170 to work in.

| | Depth from the rear wall |
|---|---|
| Flange faces | 267 |
| Plenum, ~60 (about ½ a fan diameter, so the hub dead zone recovers) | 267–327 |
| One 120 on the fan panel | 327–352 |
| Collar | 352–382 |
| Two 140s on the front wall | 382–407 |
| Front wall | ~437 |

About 30 spare. A second 120 on the panel takes that to ~5, so within option A
**the front stage and a second panel fan are alternatives, not both**. The
power cables escape through the top-edge strip rather than the plenum's back
wall, so they cost no plenum depth.

### Option B — two 140s across, two deep

Four 140s, all inside the duct, no panel and no collar. Same estimated static
as C (~8.4 vs ~8.1 at scenario B) and it **degrades better**: lose one fan and
you drop a column but keep running, where a 3-stack loses a third of its
pressure *and* the dead fan becomes a restriction.

It's behind C on two things: the 280-wide transition exceeds most print beds
and needs splitting plus a sealed seam, and 280 against a 160 column means
real lateral necking where C has none. If uptime turns out to matter more than
part size, or if scenario B (below) proves real and ~8 mmH₂O isn't enough,
this is the one to come back to — it's also the base for a 2×3 six-fan version
at ~12.6 mmH₂O.

### Option F — two 120s across, two or three deep

Kept as the fallback if E is short on pressure. One 120 at scenario B sits at
61 % of free air, on the steep part of its curve, so a second fan across is
worth much more here than it was for the 140s:

| | Fans | Static, scenario B |
|---|---|---|
| 2 across × 2 deep | 4 | ~8.0 |
| 2 across × 3 deep | 6 | ~11.9 |

Behind E on two counts the user cares about: it's side-by-side, and the
transition goes to 240 wide, past a 220 bed, so it splits into two pieces with
a seam to seal. A fourth fan in series on E reaches ~10.2 with neither
problem. Come back here if four-deep still isn't enough.

### Option D — three 140s across, one deep

Considered 2026-09-22 and currently the weakest of the four, recorded so the
reasoning isn't re-derived:

- **Almost no pressure gain.** 3 across vs 2 across moved the estimate from
  ~4.2 to ~4.4 mmH₂O. Parallel width doesn't buy static, and we're already far
  enough left on the curve to be on its flat part.
- **420 against ~430 inside** is tighter than the arithmetic looks once fan
  flanges, case wall and duct walls are counted.
- **It seals off the case's only intake.** Every front position goes to the
  duct, so CPU, PSU and drives get whatever the two loud 80 mm rear exhausts
  can drag through the seams. The case goes negative-pressure and pulls
  unfiltered air through every gap, bypassing the front filter. On an EPYC
  board with a 158 mm tower cooler that's not a detail.

**At least one front position should stay with the rest of the machine** —
that conclusion survives regardless of which option wins.

### Sealing

The plenum seals onto the four flange faces, over the bore band only. The
**top-edge strip stays outside the plenum**: the 12V-2x6 plugs, their 35 of
straight cable, and the connector columns. The adapter tube's wall already
separates the bore from the power notch, so that costs nothing.

But note that **the power notch itself is an open cutout, not a seal** — there
is a large unsealed gap around the plug. That doesn't leak the plenum (it's
outside it), but it does let air out of the bay before it reaches the fins.
If that turns out to matter, the fix is a collar or closed boss in the *card
adapter*, not in the quad parts. Parked, not solved.

Leak area is the thing most likely to wreck the quad — far more than fan
placement. Four bracket-plate slots plus any escape through the plenum wall
can easily add up to more than 5548 mm².

## Test method

**Stage 0, driver bring-up.**
- Idle is about 50 W. With no forced air that's a 50 to 75 °C rise, which is
  enough to throttle. There's no RMA path, so **don't run the card bare**.
  Any fan pointed into the tail, or a desk fan into the open case, is enough.
- **Get a temperature reading working first**, from either:
  - `xpu-smi`, from the pinned LTS 2523 bundle (1.3.3 dropped Max support), or
  - the `xe` driver's sysfs:
    `/sys/class/drm/card*/device/hwmon/hwmon*/temp1_input`

**Stage 1, with the adapter.**
1. Start at 150 W with one fan. Confirm the adapter seals and the temperature
   responds.
2. Step the power up: 150 → 200 → 250 → 300 W. At each step, record GPU and
   HBM Tj, the fan rpm needed to hold it, and tokens/sec. Keep well clear of
   105 °C.
3. Drive the fan PWM from GPU temperature, never a fixed speed.

**That power curve is the deliverable.** It's what sizes the quad.

## Print settings

PETG, 0.2 mm layers, 4 perimeters, 20 % infill, no supports. Card adapter:
flange down on the bed.

## Open

- [ ] Print card adapter V2. Check that:
  - the 22 tube fits the opening
  - the bracket holes line up with the bracket mounting holes
  - the power notch clears the plug and its latch
  - the flange sits flat on the shroud end plane
- [x] V3 printed and fitted (2026-09-22). It goes in, hooked over the power
      plug. Two fixes, both in V4: bracket holes Ø3.0 → Ø3.4, and the scoop
      stops 4 short of the top-edge end to clear the header pins.
- [ ] Print V4 and confirm both fixes on the card
- [ ] Scoop length (10 or 8) and drop (5), once it's in and the fins can be seen (M2.5 or M3), and whether Ø3.0 holes pass it
- [ ] Read the Figure 6-4 impedance curve — it also settles what area the 285 LFM is referenced to, which sets the quad's fan count
- [ ] Fan size for Salmon: 120 or 140
- [x] P14 Pro PST (ACFAN00319A, 5-pack) ordered 2026-09-22. Now headed for Salmon: a 140 doesn't mount on the quad chassis' front plate
- [ ] Order P12 Pro PST (ACFAN00307A, 5-pack, ~$65) for the quad duct — 4 deep plus a spare
- [ ] Check whether the front grill can be cut out. Worth ~1.2 mmH₂O at scenario B, for free
- [x] Comb V1 printed and fitted (2026-09-23). One rigid part spans the four cards on the 40.64 pitch, and 2.0 teeth enter all three gaps
- [ ] Quad fan layout: options A–G are all live. Leaning E (1 across × 3–4 deep, 120s) for the stack, with G (the tail box) as the shape around it. Figure 6-4 decides three deep vs four
- [x] Card thickness settled at 38.64 by comb V1 (2026-09-23), not the datasheet's 34.35. Gap between cards is 2.0
- [ ] Redo the scenario B flow and the static estimates on 53 CFM rather than 47, now the card's frontal area is known
- [x] The 12 of case-wall clearance is past card 4's shroud side: 12 by tape at the top edge (2026-09-28)
- [x] Motherboard's front edge is 20 in from the card tail plane (2026-09-28), so the floor in front of the tails is clear
- [ ] Floor and side-wall standoffs: thread size and positions
- [ ] Which front grill positions sit in front of the card column, and how many the tail box can take while leaving one for the rest of the machine
- [ ] Identify the row of modules in sheet-metal brackets between the front bar and the board — it sits in the tail box's footprint
- [ ] Does the front bar's down-turned flange foul the duct? If yes, option A comes back into play
- [ ] Design the Salmon flare. V1 drawn 2026-10-02 (`cad/flare.py`), a first draft to print and fit: one 140, 130 past the tail end with the fan on
- [ ] Measure the bore centre's height above the chassis floor with a card installed. The 52-to-70 estimate is what decides whether the panel 120s sit on the floor or need a riser
- [ ] Test print the card adapter with a +Z stub, to pick the print orientation
- [ ] Decide whether the power notch gap needs sealing, and if so add a collar to the card adapter
- [ ] Confirm the front wall behind the door is open enough for two 140s

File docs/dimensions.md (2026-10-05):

# Max 1100 Dimensions

All mm. Names follow [Terminology](../README.md#terminology). See also
[cooling](cooling.md) and [the chassis](rackchoice-4u.md).

## Card

Intel Data Center GPU Max 1100 datasheet, document 817799.

| | |
|---|---|
| Length | 266.7 (312 with the extension bracket, which reaches 45 past the tail) |
| Height | 111.15 (PCIe full height) |
| Thickness | **38.64** measured (2026-09-23), not the datasheet's 34.35 — see below |
| Mass | 1308 g card, 35 g extension bracket |

### Thickness: 38.64, not 34.35

The datasheet's "34.35, dual slot" is not the physical envelope. **Settled by
comb V1** on 2026-09-23: the comb's spine is 160.56 long, cut as
3 × 40.64 + 38.64, and it sits **flush with both outer faces** of the installed
column — card 1's PCB side at one end, card 4's shroud side at the other. At
34.35 the column would be 156.27 and the comb would have overhung by 4.3,
which is not something you miss. So:

| | |
|---|---|
| Card envelope, PCB side → shroud side | **38.64** = 160.56 − 3 × 40.64 |
| Gap between adjacent cards | **2.0** = 40.64 − 38.64 |

38.64 also sits just inside the PCIe double-width envelope of 39.37, which is
where a 300 W dual-slot card would be expected to land; 34.35 would be unusually
thin.

Two earlier readings pointed the other way and both were weaker than they
looked:

- The tail-end tape stack — shroud cover → PCB 31.75, plus a guessed PCB and
  bracket plate — lands near 34.35. Three rough numbers stacked, and the guess
  was doing the work. The real PCB-side stack past the PCB is ~6.9.
- A 2 shim reading "snug in some, loose in others" was read as possibly
  catching a proud bracket plate. It was just the gap, with the variation you
  get across four cards in real slots.

**One caveat on where it was measured.** The comb's teeth occupy the last 25 of
the card before the tail end plane, so 2.0 is confirmed *there* — which is the
region a tail wall seals in. A tooth running deeper along the card could find
the gap opening up where the extension bracket plate ends. Check before
lengthening a tooth much past 45.

## Tail end

Katie's measurements, with the V2 fit adjustments where noted. Positions are
given from the opening's edges, which the card adapter's tube fills.

| | |
|---|---|
| Opening, finger edge → top edge | 76 |
| Opening, PCB side → shroud side | 22 (V2; Katie's V1 used 20) |
| Fin face, in from the shroud end plane | 37 to 39 |
| Stack, shroud side → PCB side | shroud cover, fins, copper, base plate, PCB, bracket plate |
| Shroud cover (outside) → base plate | 27.8 (tape) |
| Shroud cover → PCB | 31.75 (tape) |

## Bracket mounting holes

The two threaded holes the extension bracket screws into. The card adapter's
bracket holes sit over them.

| | |
|---|---|
| Spacing | 19 center to center, in a line running PCB side → shroud side |
| Screw axis | Along the card's length (screws go in from past the tail) |
| From the opening's finger-side edge | 4, toward the finger edge (V2) |
| From the opening's PCB-side edge | 1 toward the PCB side, and 18 toward the shroud side (V2) |
| Screws | Torx T8. The adapter's holes are Ø3.4; Ø3.0 was too tight to start the screws (V3 fit, 2026-09-22) |

## Extension bracket

Measured 2026-10-02 (tape, with photos) on a card with adapter V3 fitted, so
"past the flange face" is from V3's flange face, 2 past the shroud end plane.
The tape readings are to about ±1.

The bracket's outer end is a **bar**: a strip lying parallel to the PCB side,
running finger edge → top edge, with a hole at each end. These are the holes
the flare bolts to. They must stay reachable: a stabilizer may bolt to them
too.

| | |
|---|---|
| Bar | 96 (finger edge → top edge) × 10 (along the card's length) |
| Bar holes | 88 center to center. Round hole at the finger-edge end, slot at the top-edge end |
| Bar holes, past the flange face | 40, so 42 past the shroud end plane |
| Bar holes, in from the bar's outer edge | 3, so the bar runs 35 to 45 past the shroud end plane |
| Round hole, from the bracket mounting holes | about 4 toward the finger edge (by eye) |
| Bar, from the card's PCB-side face | about 1 inside it: with the card resting PCB side down there is ~1 under the bar |
| Bar thickness | about 1 (user, 2026-10-02), so its shroud-facing face is about 2 inside the card's PCB-side face |
| Bar hole diameter, slot size | |
| Flange's PCB-side edge against the card's PCB-side face | Flare V1 assumes flush, which puts the bar's shroud-facing face 12 from the tube |
| Gusset (the standing triangle at the finger-edge end) | stops 32 past the flange face, so 34 past the shroud end plane |

## Salmon

| | |
|---|---|
| Tail end → the case's front fans | **135** (user, 2026-10-02). Replaces the 125 derived from the case's 392 GPU clearance |
| Limit for the flare plus its fan, past the tail end | 130, leaving 5 |

## Power

- 12V-2x6 sits outside the opening, on its PCB side, at the top-edge end.
- The card adapter's power notch clears it: 24 × 14, running from the
  flange's PCB-side edge to the tube. Its top-edge side lines up with the
  bore's inside face.
- The plug goes in axially and the cable exits straight out past the tail.
  Allow about 35 of straight cable before any bend.
- Check the latch can still be reached with the card adapter fitted.
- The notch is an **open cutout, not a seal**: there is a large unsealed gap
  around the plug (V4 on the card, 2026-09-22). It doesn't open into the bore
  — the adapter tube's wall separates them — but it does let air out of the
  bay before it reaches the fins. Not yet measured, and not yet known to
  matter.

## Inside the bay

- A row of header pins runs near the **top-edge end**, 2 to 3 in from that side
  of the opening. Anything reaching deeper than the tube has to stay clear of
  them: the V3 scoop fouled them and had to be cut back by hand (2026-09-22).
  V4 stops the scoop 4 short of the top-edge end.
- The fin face is 37 to 39 in, so there's open bay in front of it.

## Quad column

Four cards in the RackChoice 4U, board slots 1, 3, 5, 7, standing upright,
tails toward the case front. Measured on the installed cards 2026-09-23 (tape
and shim) except where noted. See [cooling](cooling.md#column-geometry) for
the derived bore positions.

| | |
|---|---|
| Slot pitch | 40.64 (PCIe, 2 × 20.32). Exact: the slots set it |
| Column width, card 1's PCB side → card 4's shroud side | **160.56** — 160 by tape, confirmed to the comb's 160.56 (flush both ends) |
| Gap between adjacent cards | **2.0**, over the last 25 before the tail end plane. See [thickness](#thickness-3864-not-3435) |
| Card envelope | 38.64, not the datasheet's 34.35 |
| Card top edge, above the case floor | **127** (tape), PCB side |
| Card finger edge, above the case floor | 15.85 = 127 − the card's 111.15 (derived) |
| Top edge is a step | The shroud side's top edge sits **1 to 2 lower** than the PCB side's. Matters for anything sealing down onto the card tops |
| Flange thickness vs pitch | 38 against 40.64, so **2.64 between adjacent flanges** |
| Gap between adjacent bores | 21.6, past the flange (Z > 2) |
| Extension bracket plate | Occupies that 21.6 from Z = 0 to +45, one per card |

Leak area, for anything that seals the column: three gaps at 2 × 111.15 is
**~670 mm²** against 5548 of total bore. The gap is a nearly free path — a
111-tall channel running the card's full 267 length is worth well under
0.1 mmH₂O against a fin stack worth several — so unsealed it takes the air
even at 670.

**Confirmed on the cards, 2026-09-23.** Comb V1 (`cad/comb.py`), a rigid
printed bar 160.56 long with three 2.0 teeth on the 40.64 pitch, dropped onto
the four installed cards and fitted. Four results:

- **The column is 160.56 and the card is 38.64.** The spine came out flush
  with both outer faces, so the comb is a go/no-go gauge on the column width,
  not just a fit test. See [thickness](#thickness-3864-not-3435).

- **Pitch accumulates to nothing across the column.** Four cards in a real
  board in a real case take a single rigid part, no per-card float needed at
  the top. This was the biggest unknown in the [tail
  box](cooling.md#option-g--the-tail-box) and it went the right way. It also
  softens the argument that the plenum *must* be separate from the adapters —
  that argument still holds on the axial and service grounds, but not on
  lateral tolerance.
- **2.0 is the universal tooth.** All three gaps took it as printed, no
  trimming, so the printed-over-nominal worry didn't bite.
- **The spine seats on the four top edges** at 127.

## RackChoice 4U chassis

Measured on the case, 2026-09-23 (tape). Chassis research and the photo-scaled
estimates are in [rackchoice-4u](rackchoice-4u.md); these are the numbers
taken with the case in hand. The front wall's inner face is the grill plane.

| | |
|---|---|
| Grill → extension bracket tip edge | **120** (tape). Was estimated 125 from photos |
| Grill → flange faces (derived) | 165 = 120 + the bracket's 45 past the tail |
| Lower fan screw hole, above the case floor | 25.4 (1") |
| Bottom of the power buttons, above the upper screw hole | 10 (1 cm) |
| Top of the power buttons, above the case floor | **157** (tape, photo, 2026-09-28) |
| Motherboard's front edge | **20** in from the tail end plane: the cards reach 20 past it (2026-09-28). The floor in front of the tails is clear |
| Front grill positions | 3 × 120 side by side, perforated, screw holes top and bottom |
| Threaded standoffs, case floor | ~5 proud. Six of them, the spare motherboard mounting points. Thread and positions not taken |
| Threaded standoffs, slot-side wall | ~5 proud (photo, 2026-09-23). Thread not taken |
| Standoff on the case wall past card 4 | **60** from the front wall, **~125** above the case floor (tape, photo, 2026-09-28). A second one sits lower, around 50, position not taken |
| Column datum → case wall | **172** (tape, 2026-09-23) |
| Clearance past the column, derived | 11.44 = 172 − 160.56 |
| Card 4's shroud side → case wall, at the top edge | **12** (tape, photo, 2026-09-28) |

**The column is not against the case wall.** There is about **12** of
clearance past **card 4's shroud side**, measured directly at the top edge and
agreeing with the 11.44 derived from the 172. That's what the tail wall and
the box's side panel have to close: card 1's side of the box seals against a
card face, card 4's side against sheet metal.

Derived from those, above the case floor:

| | |
|---|---|
| 120 fan upper screw hole (105 spacing) | 130.4 |
| Bottom of the power buttons | 140.4 |
| 120 fan body | 17.9 to 137.9, centre 77.9 |
| 140 fan upper screw hole (124.5 spacing) | 149.9 — **9.5 into the power buttons** |

**A 140 fan does not mount on the front plate.** Its upper screws fall inside
the power button cutout. The 120 clears with 10 to spare.

## Not yet measured

| | |
|---|---|
| Fin throat, width × height | Estimated from photos: 15–20 × ~68 |
| Fin count / fin pitch | |
| Tallest header above the PCB | |
| Gap between cards past the extension bracket plate | 2.0 is confirmed over the last 25 only. Deeper than ~45 along the card it may open up |
| Floor and side-wall standoffs | Thread size, and positions from the card tail plane and the slot-side wall |
| Bore centre above the chassis floor, card installed | Estimated 52–70. Now one measurement away: the finger edge is 15.85 above the floor, so only the bore centre above the finger edge is missing. The front fan's centre is fixed at 77.9, so this sets how far a duct has to slant |
| Front grill open fraction | Assumed 55 % for the inlet-loss estimates. Worth checking, and whether the grill can be cut out — it's worth ~1.2 mmH₂O at scenario B |
| Power notch gap around the plug | Visibly large (photo, 2026-09-22); never calipered |

## Other

- The bay also has debug and management headers: CNSPI1, CNAMC1, SWAMC1.
- The black strip along the top edge may be a removable bridge connector cover.
- The extension bracket's inner hole is riveted.

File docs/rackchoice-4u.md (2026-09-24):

# RackChoice 4U chassis

The case the quad goes in. All mm. Names follow
[Terminology](../README.md#terminology). See also [dimensions](dimensions.md)
and [cooling](cooling.md).

Moved here from SCNVault on 2026-09-23, because the chassis and the duct
design stopped being separable — the tail box is shaped by the case, not by
the card. The vault keeps a pointer at
`Projects/QuadBox/RackChoice 4U Fit`. **The case is a QuadBox part**, not a
single-card one; it sat under `Max 1100 Notes` until the move. Host, driver
and project-log notes stay in the vault.

**Numbers taken with the case in hand live in
[dimensions](dimensions.md#rackchoice-4u-chassis).** What's here is the
research, the fit reasoning and what's still unmeasured. Anything marked
*(photo)* is scaled from the listing's top-down photo against the 438 width,
good to about ±10, and should be replaced as it gets measured.

## The case

- Amazon.ca ASIN B0BXJ5HF2W, $333 CAD, sold by CICHENG INC, ships from Amazon
- External 438 W × 178 H × 465 D (483 with rack ears). 6.94 kg. Zinc-coated steel
- EATX / ATX / mATX / Mini-ITX
- 8 full-height expansion slots, perforated covers
- 1 ATX PSU bay, PSU stands on edge (about 86 wide) at the opposite side from
  the slots
- 2 × 80 mm rear exhaust fans included (reviews: loud)
- **No front fans or fan wall.** Front is a honeycomb door with a filter
  behind it; the front plate behind it carries 3 × 120 positions
- Two screwed-in crossbars at lid height: a rear bar with six round holes, and
  a plain front bar (the "elevated 360 radiator" mount, unconfirmed)
- Threaded standoffs about 5 proud on the case floor and on the slot-side wall
- 2 × 3.5 internal. No sliding rails; use a shelf
- Reviewer fit a 158 mm Noctua NH-U12S, just touching the lid
- No manual

## What fits (assumes ROMED8-2T, Node 1)

- **Slots:** 4 dual-slot cards in board slots 1, 3, 5, 7. Slot 7's card needs
  the 8th case slot, which this case has
- **Width:** ATX board 305 + PSU on edge ~86 = ~391 against ~430 inside
- **Orientation:** cards stand upright, tails facing the case front, fins I/O
  end to tail end
- **Depth:** inside depth ~437 *(photo)*. Card tails at ~267 from the rear
  wall, leaving ~150 to 170 in front of them
- **Height:** inside ~170. Card top edge **127** above the floor (measured)
- **Exhaust:** cards exhaust through the perforated slot covers; the 80 mm
  pair covers the CPU zone

## Chassis layout *(photo)*

| Feature | From inside of rear wall |
|---|---|
| Rear bar (six holes) | 110 to 195 |
| Card tail | ~267 |
| Front bar | 276 to 366, centre ~321 |
| Extension bracket tip (card + 45) | ~312 |
| Front wall | ~437 |

The card column sits against the slot-side wall, roughly 0 to 160 in.

**The motherboard's front edge is the one that matters and isn't measured.**
An EEB board is 330 deep, so on this layout it would reach ~63 past the card
tails — meaning the first ~63 in front of the tails is over the board, not
over free floor, and only beyond that can anything bolt down. That sets where
the tail box's floor piece can start and whether a comb can be supported from
below. See [cooling](cooling.md#option-g--the-tail-box).

## Tail support

The tails must be supported. Each extension bracket has a screw hole at the
top that locates into a guide.

**The bracket tips land under the front bar** (~312 against a bar spanning 276
to 366), about 10 behind its centreline. No need to relocate it front to back.

**The gap is vertical.** The bar is at lid height (~170); the bracket hole is
near the card top edge (127). Expect a 40 to 50 drop.

### Option 1: hanging card-guide rail

- Aluminium angle, 20×20 or 25×25, running side to side under the front bar
- Hung from the bar on two M4 standoffs or spacers, cut to the measured drop
- **Slotted** mounting holes to take up the ±10 depth uncertainty
- Four holes at **40.64 pitch** (2 × 20.32), one per card
- **Drill in place:** fit the four cards, clamp the rail to the bracket tips,
  mark through, drill. Absorbs slot tolerance

If the bar turns out badly placed: it is screwed at each end, so drill two new
holes per side wall and move it. Still hang from the bar rather than running a
wall-to-wall rail, since the card column sits against one wall and the far end
would float mid-case.

### Option 2: the tail box carries them

Added 2026-09-23. If the quad goes the [tail box](cooling.md#option-g--the-tail-box)
route, the box's comb does this job instead: teeth between the cards locate
them laterally and a cradle under each finger edge takes the weight, with the
box bolted to the floor standoffs and the front wall. No rail, no drilling,
and the extension brackets may come off entirely. Both are live.

Whichever wins, support the cards **vertically and with clearance, not by
clamping**. The box is registered to the case floor and the cards to the
board; a rigid tie between them preloads the PCIe connectors with whatever the
tolerance chain gives.

### Conflict with the duct design

The vault's old `cooling` decision 4 bolted the duct to the two ledge holes
and **replaced** the extension bracket. The card adapter instead uses the
bracket's **own screws** to clamp itself on, so the bracket stays and that
conflict doesn't arise. All of it is still being brainstormed — if the
bracket-replacing approach comes back, this section describes what it costs.

What still applies:

- Each bracket plate runs through the 267 to 312 zone in its card's plane, so
  anything spanning the column needs a slot or cutout per card. It sits in the
  gap between adjacent bores, which is exactly where a plenum would want to
  put material
- With a card adapter per card and a plenum beyond it, the slip joint is what
  absorbs the slot-to-slot tolerance, so the rail's "drill in place" trick and
  the plenum no longer have to agree on anything

## Open issues

1. **No intake fans.** The fan wall or plenum is ours to build
2. **PSU:** one ATX bay. Full load ~1.5 kW; at the 150 W cap ~850 W. Needs
   **four 12V-2x6 leads**, native or 2×8-pin to 12V-2x6. No 90° adapters.
   Count leads before buying. The PSU breathes case air, which is fine because
   the cards exhaust out the rear
3. **Xe Link bridges vs the rear bar.** The rear bar's down-turned flange may
   leave only ~25 above the card tops. Remove the bar if it fouls. Bridges are
   not needed for bring-up
4. **Slot 1 card vs DIMMs and CPU cooler** on the ROMED8-2T. Not confirmed
5. **Front wall behind the door:** open or solid? Drill if solid
6. **Power cables:** 35 straight past each 12V-2x6 before a bend. The tightest
   part of the layout, and it decides how anything spanning the card tops
   installs — the comb slides on from the case front, so it goes on before the
   cables
7. **What the row of modules in sheet-metal brackets between the front bar and
   the board is** (photo, 2026-09-23). Stock fan wall? Drive cages? It sits in
   the tail box's footprint. If it stays, the box doesn't fit as sketched

## Build path

- **Stage 0 (bring-up):** four cards, 150 W cap and watchdog on all four. Two
  P14 Pros on the floor in front of the tails blowing toward the I/O ends,
  cardboard shroud. Enough for driver bring-up and first idle and load numbers
- **Stage 1:** a plenum or tail box across the four tails. Fan layout is in
  [cooling](cooling.md#quad), where options A–G are all live. Note the bore is
  73 × 19, so the old "four spigots, 26 × 76 × 32" sizing needs redoing
  whichever option wins

## Measure on arrival

- [x] Bracket tip distance from the front grill — **120**, 2026-09-23
- [x] Card top edge above the chassis floor — **127** (PCB side), 2026-09-23
- [x] Front plate fan positions and screw heights — 2026-09-23, and they rule
      out a 140
- [ ] **Bore centre above the chassis floor, card installed.** Estimated 52 to
      70. Now one measurement away: the card's finger edge is 15.85 above the
      floor, so all that's left is the bore centre above the finger edge
- [ ] **Motherboard front edge, from the card tail plane.** Decides where the
      tail box's floor can bolt down
- [ ] **Floor and side-wall standoffs**: thread, and positions relative to the
      card tail plane and the slot-side wall
- [ ] Front bar underside height above floor; flange or not
- [ ] Front bar position front to back (checks 276 to 366)
- [ ] Inside depth along the card column
- [ ] Gap under the rear bar, for Xe Link bridges
- [ ] Front wall behind the door: open area, and whether the grill can be cut out

## Sources

- [Amazon.ca listing](https://www.amazon.ca/dp/B0BXJ5HF2W)
- [RackChoice product page](https://rackchoice.net/Liquidcoolingchassis/111.html)
- SCNVault `Projects/QuadBox/` — the appliance this case is for: `hardware`,
  `bom`, `orders-and-inventory` (where the case was ordered), and the pointer
  stub this note left behind
- SCNVault `Projects/Max 1100 Notes/` — the single-card work: project log,
  host and driver notes

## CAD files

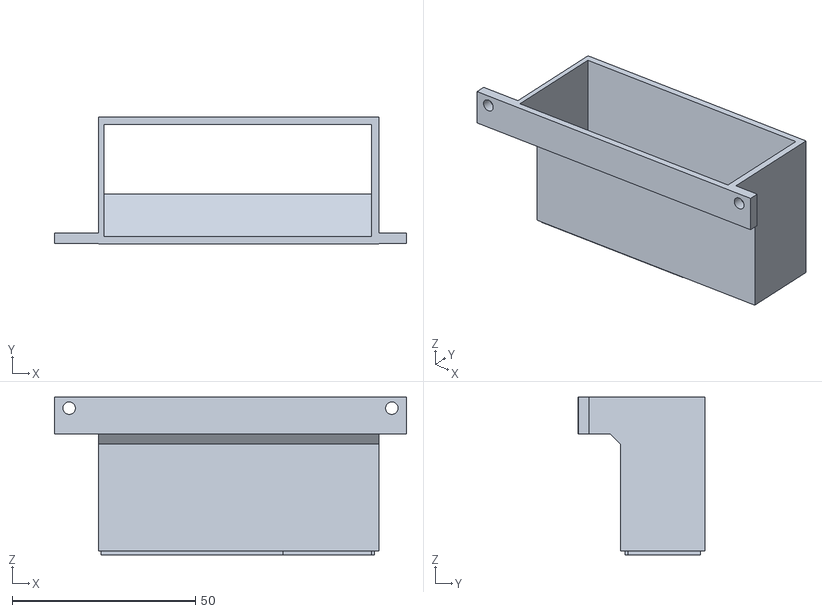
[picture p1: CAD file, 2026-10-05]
stl/max1100-flare-fit-test-v2.stl
96.0 x 34.5 x 43.0

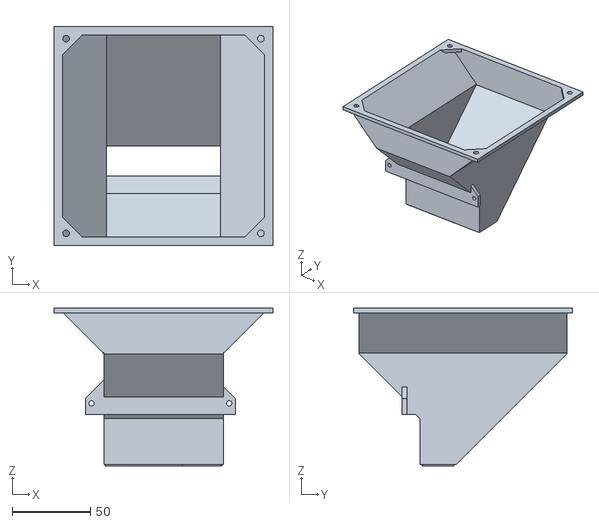
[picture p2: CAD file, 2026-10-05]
stl/max1100-flare-v2.stl
140.0 x 140.0 x 100.9

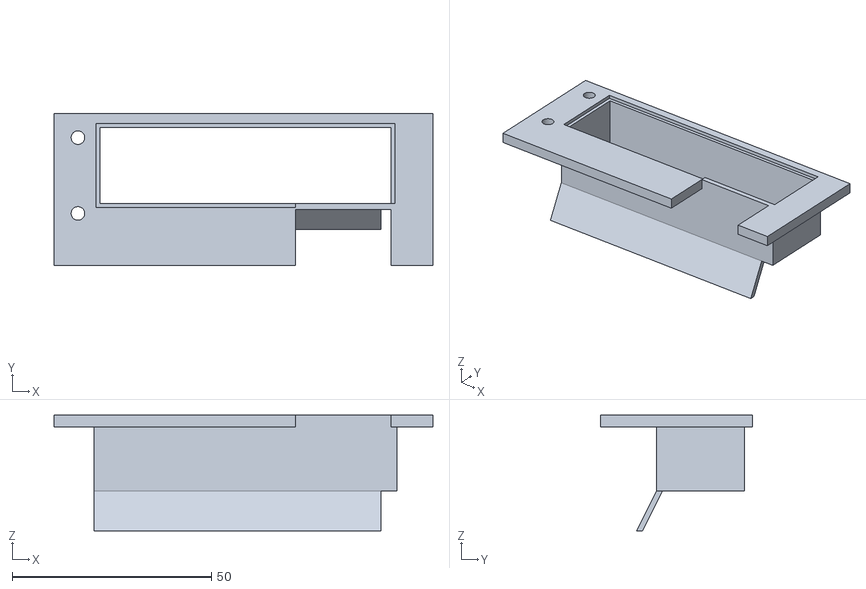
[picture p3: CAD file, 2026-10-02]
stl/max1100-card-adapter-v4.stl
95.0 x 38.0 x 29.0

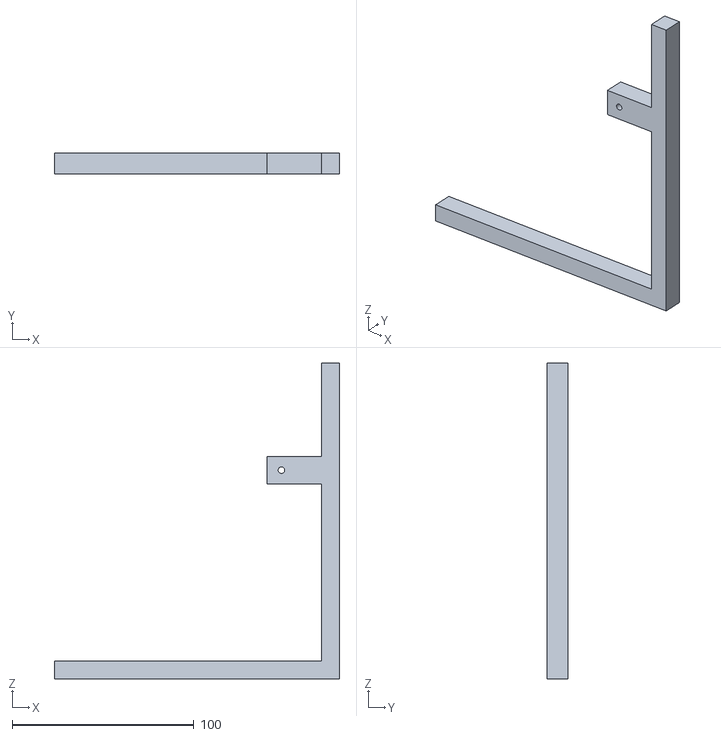
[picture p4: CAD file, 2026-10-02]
stl/max1100-case-side-rib-v1.stl
157.0 x 11.5 x 174.0

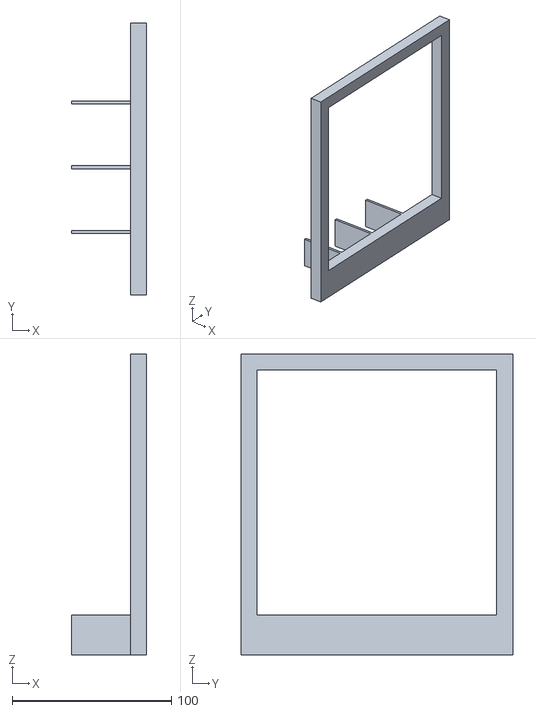
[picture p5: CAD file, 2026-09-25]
stl/max1100-tail-box-gauge-v1.stl
47.0 x 171.0 x 189.0

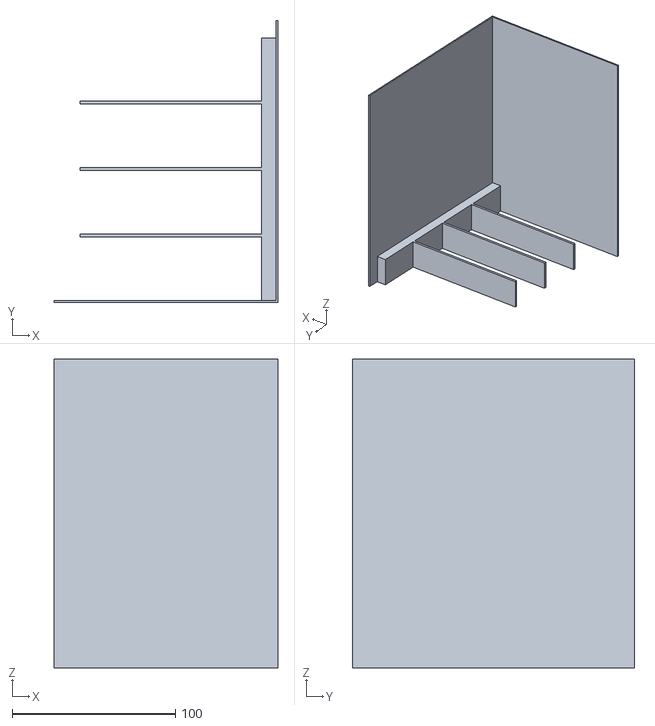
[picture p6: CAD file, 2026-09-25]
stl/max1100-tail-box-demo-v1.stl
137.0 x 172.2 x 189.0

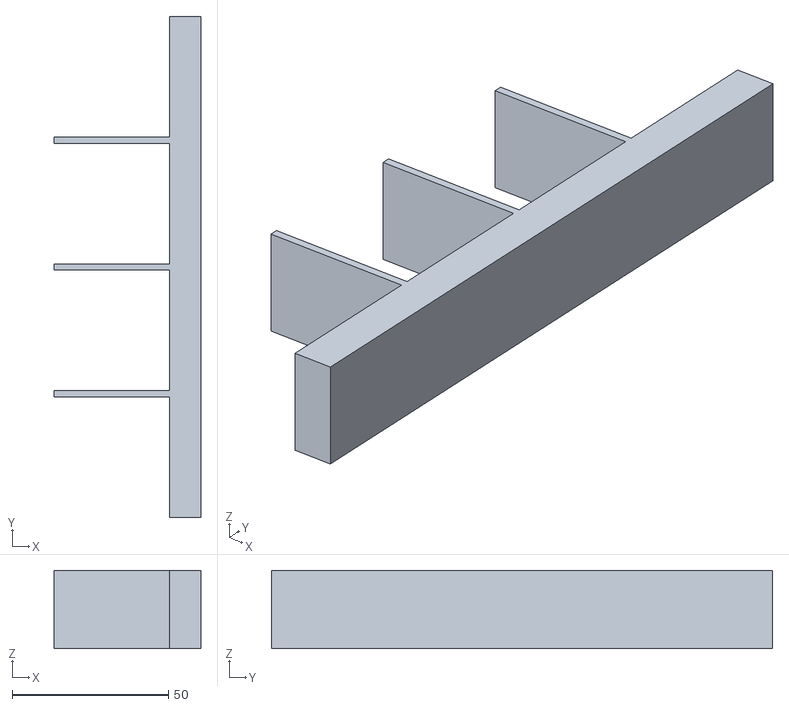
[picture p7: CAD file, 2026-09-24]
stl/max1100-comb-v1.stl
47.0 x 160.6 x 25.0

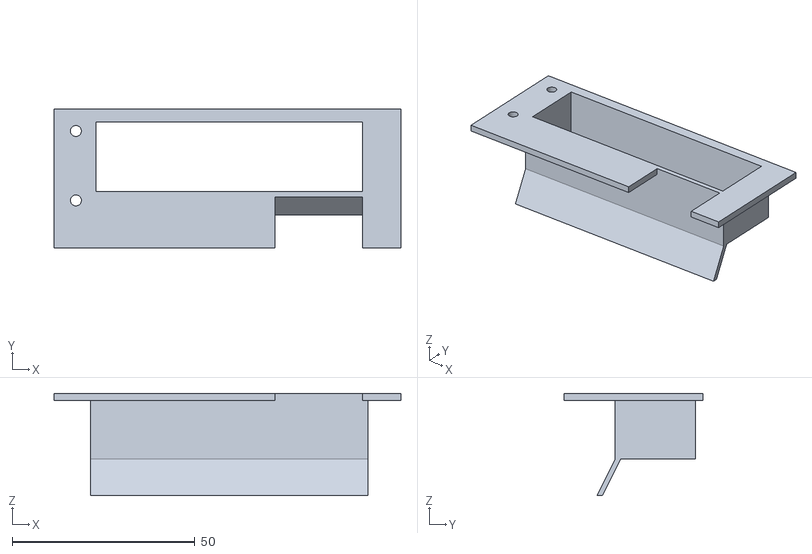
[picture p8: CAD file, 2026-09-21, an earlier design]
stl/archive/max1100-card-adapter-v3.stl
95.0 x 38.0 x 28.0

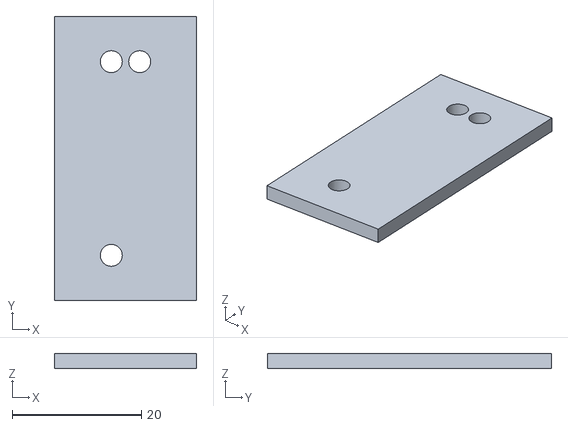
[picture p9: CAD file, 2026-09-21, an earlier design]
stl/archive/max1100-hole-coupon.stl
22.0 x 44.0 x 2.40

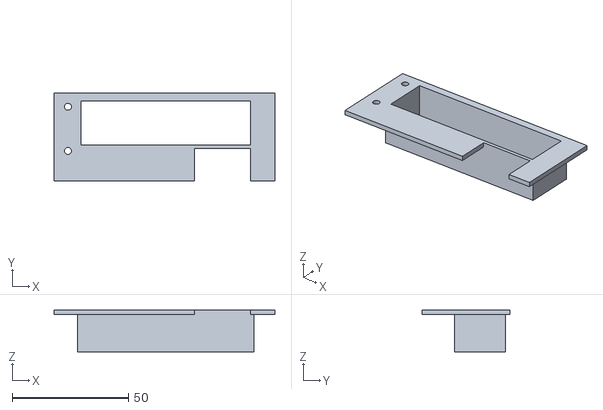
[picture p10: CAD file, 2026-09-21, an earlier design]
stl/archive/max1100-card-adapter-v2.stl
95.0 x 38.0 x 18.0

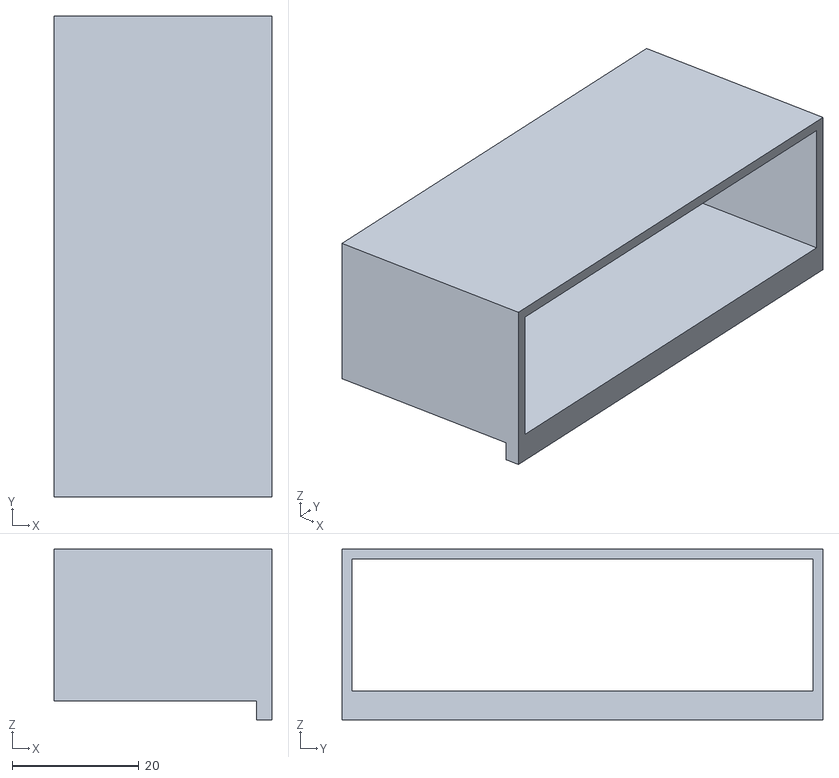
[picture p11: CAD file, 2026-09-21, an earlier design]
stl/archive/max1100-box-fit-test-v2.stl
34.4 x 76.0 x 27.0

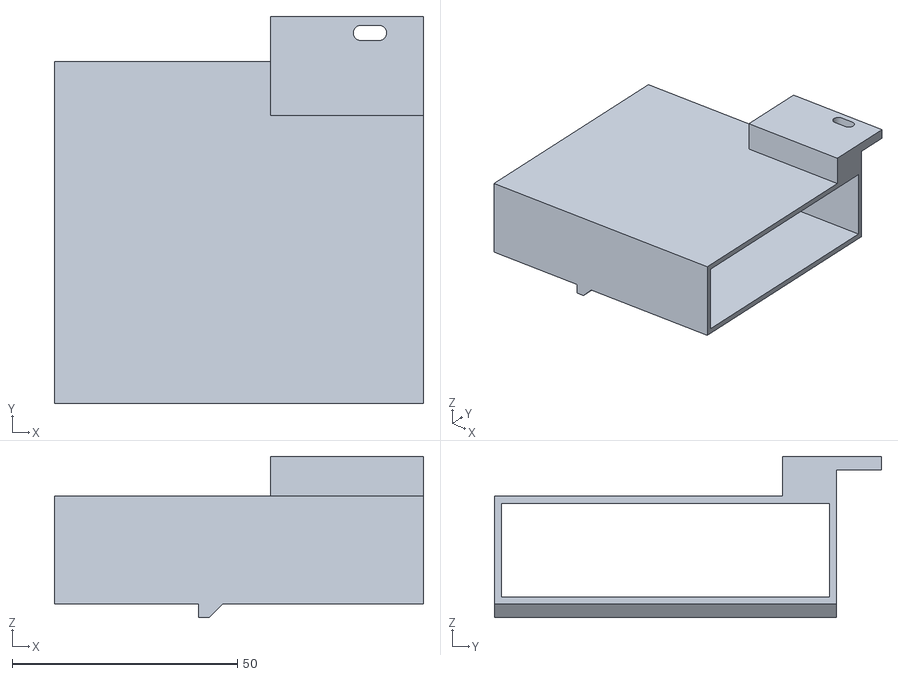
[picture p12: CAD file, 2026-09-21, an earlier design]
stl/archive/max1100-duct-card.stl
82.0 x 86.0 x 35.8

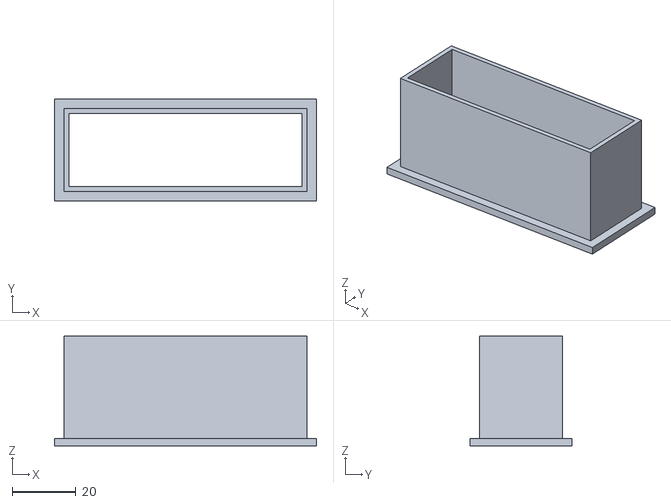
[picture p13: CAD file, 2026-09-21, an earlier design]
stl/archive/max1100-box-fit-test.stl
82.0 x 32.0 x 34.4

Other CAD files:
stl/archive/max1100-flare-fit-test-v1.stl
stl/archive/max1100-flare-v1.stl
rhino/1100-singleshroud-v1.3dm
rhino/archive/max1100-card-adapter-v2.3dm
rhino/archive/max1100-card-adapter-v3.3dm
rhino/archive/max1100-flare-fit-test-v1.3dm
rhino/archive/max1100-flare-v1.3dm
rhino/max1100-card-adapter-v2.3dm
rhino/max1100-card-adapter-v3.3dm
rhino/max1100-card-adapter-v4.3dm
rhino/max1100-case-side-rib-v1.3dm
rhino/max1100-comb-v1.3dm
rhino/max1100-flare-fit-test-v2.3dm
rhino/max1100-flare-v2.3dm
rhino/max1100-tail-box-demo-v1.3dm
rhino/max1100-tail-box-gauge-v1.3dm

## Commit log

2026-09-21 Set up repo: card adapter CAD, docs, terminology
    - Card adapter V2 (cad/card_adapter.py), built on Katie's Rhino model
    (rhino/1100-singleshroud-v1.3dm): tube 22, bracket holes moved 1 toward
    the finger edge and 1 toward the shroud side, power notch 24 x 14.
    - cad/profiles.py writes each part as a native Rhino extrusion (.3dm) and a
    watertight STL; cad/check_v1.py confirms V1 reproduces Katie's file.
    - README terminology (card ends, edges, sides, views, CAD frame) so the card
    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
    [1100-singleshroud-v1.3dm, max1100-box-fit-test-v2.stl, max1100-box-fit-test.stl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]
2026-09-21 Card adapter V3: angled scoop on the PCB-side wall
    The tube's PCB-side wall carries on 10 past the tube's end, angled 5 toward
    the PCB side, to spread air onto the fins on that side and cut leakage back
    out through the power notch. Draft; length and drop are first guesses.
    - profiles.Slab gains axis="x" for walls that slope in Y as they go in Z.
    The STL pulls X-slab ends in 1 µm so coplanar faces don't break the union.
    - Build writes V2 and V3; V2 geometry unchanged, V1 check still passes.
    - Scoop added to README terms, cooling notes and the Rhino file index.
    [max1100-card-adapter-v3.3dm, max1100-card-adapter-v3.stl]
2026-09-22 Card adapter V4: Ø3.4 bracket holes, scoop clear of the header pins
    V3 printed and fitted on the card 2026-09-22. Two problems, fixed here:
    - Bracket holes Ø3.0 → Ø3.4 (M3 clearance); Ø3.0 was too tight to start
    the screws.
    - The scoop fouled a row of header pins near the top-edge end, 2 to 3 in
    from that side, and had to be cut back by hand. It now stops 4 short of
    the top-edge end for its whole depth.
    Both card facts are recorded in docs/dimensions.md. make parts now writes
    only CURRENT; older versions stay in git as the record.
    [max1100-card-adapter-v4.3dm, max1100-card-adapter-v4.stl]
2026-09-22 Quad ducting: four fan layout options, terminology, fan choice
    Brainstorming session on the piece past the card adapter. Docs only; no CAD
    touched, so nothing to regenerate.
    The one thing settled is that the card adapter stays its own piece, bolted per
    card by the extension bracket, with a plenum beyond it. Everything else is
    recorded as a live option, including the ones currently behind, with the
    reason they're behind so they can be picked back up.
    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
2026-09-24 Comb V1: one part spans the four cards, and the card is 38.64
    Comb V1 printed and fitted to the four installed cards (2026-09-23). A rigid
    spine with three 2.0 teeth on the 40.64 pitch:
    - Pitch accumulates to nothing across the column, so a single rigid part spans
    four cards in a real board in a real case. That was the biggest unknown in
    the tail box idea. It also softens the case for splitting the plenum from the
    adapters -- that split still stands on screw access and card service, but no
    longer on lateral tolerance.
    - 2.0 teeth entered all three gaps as printed, over the last 25 before the tail
    end plane.
    - The spine came out flush with both outer faces of the column, which make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
    [max1100-comb-v1.3dm, max1100-comb-v1.stl]
2026-09-25 Tail box gauge V1 and demo V1
    Gauge: Comb V1 plus an open ring at card-top height, out to the case wall
    (172) and the front plate (165), both 1 short so the gap is the reading.
    Fit test for option G, not yet printed.
    Demo: a show model of the tail box, not for use. An upside-down L closed
    by the case wall: a 1.2 wall to the floor against card 1's PCB side, a 1.2
    lid out to the case wall, and the comb's teeth run down to the finger edge
    so they seal the full gap. Held on by the teeth. Printing now.
    [max1100-tail-box-demo-v1.3dm, max1100-tail-box-demo-v1.stl, max1100-tail-box-gauge-v1.3dm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]
2026-10-02 created side rib for quadbox
    [max1100-case-side-rib-v1.3dm, max1100-case-side-rib-v1.stl]
2026-10-02 new version of the card adapter with a little inset for the next part
    [max1100-card-adapter-v4.3dm, max1100-card-adapter-v4.stl]
2026-10-02 Archive card adapter V2 and V3
    Move their .3dm and STL into rhino/archive/ and stl/archive/; V4 is the
    only card adapter left in rhino/ and stl/. Docs point at the new paths.
    [max1100-card-adapter-v2.3dm, max1100-card-adapter-v2.stl, max1100-card-adapter-v3.3dm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]
2026-10-05 Flare V2 and its fit test, for one 140 fan in Salmon
    cad/flare.py draws the flare from card adapter V4 to the fan, using
    extrusions only: a lip into the adapter's seat, a two-stage 45° taper, a bar
    pad and ears bolted to the extension bracket's bar, and a 140 fan plate. It
    ends 130 past the tail end with the fan on. FIT_V2 cuts it off at the bar to
    test both joints.
    V1 and its fit test are archived. The V1 fit test was printed 2026-10-05 and
    its lip didn't drop into V4's rebate; that's not diagnosed yet. V2 makes the
    PCB-side wall 2 thick across the power notch.
    docs/dimensions.md gets the extension bracket's bar (tape, 2026-10-02) and
    Salmon's 135 from the tail end to the front fans.
    Co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
    [max1100-flare-fit-test-v1.3dm, max1100-flare-fit-test-v1.stl, max1100-flare-fit-test-v2.3dm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]
